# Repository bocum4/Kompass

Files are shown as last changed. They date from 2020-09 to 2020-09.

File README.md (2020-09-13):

  ____   ____   _____ _    _ __  __          
 |  _ \ / __ \ / ____| |  | |  \/  |   /\    
 | |_) | |  | | |    | |  | | \  / |  /  \   
 |  _ <| |  | | |    | |  | | |\/| | / /\ \  
 | |_) | |__| | |____| |__| | |  | |/ ____ \ 
 |____/ \____/ \_____|\____/|_|  |_/_/    \_\

KOMPASS DIGITAL MINI SYTNH.

Related Project Files. 

Este proyecto está basado en el Nebulophone de Dr. Bleep (Nos quitamos el sombrero ante su ingenio). 

https://bleeplabs.com/product/nebulophone/

Se modificó el ruteo de los pines del ATMega para permitir la adición de un sensor capacitivo MPR121
como motor principal del teclado háptico y re-diseñamos la interfaz según nuestros intereses. Todos 
los archivos de programación y manufactura se hacen disponibles aquí bajo la misma licencia 
del proyecto original. 

Creative Commons Attribution-ShareAlike 3.0 Unported License 

Para mas info: contacto@bocuma.mx 

#somosbocuma

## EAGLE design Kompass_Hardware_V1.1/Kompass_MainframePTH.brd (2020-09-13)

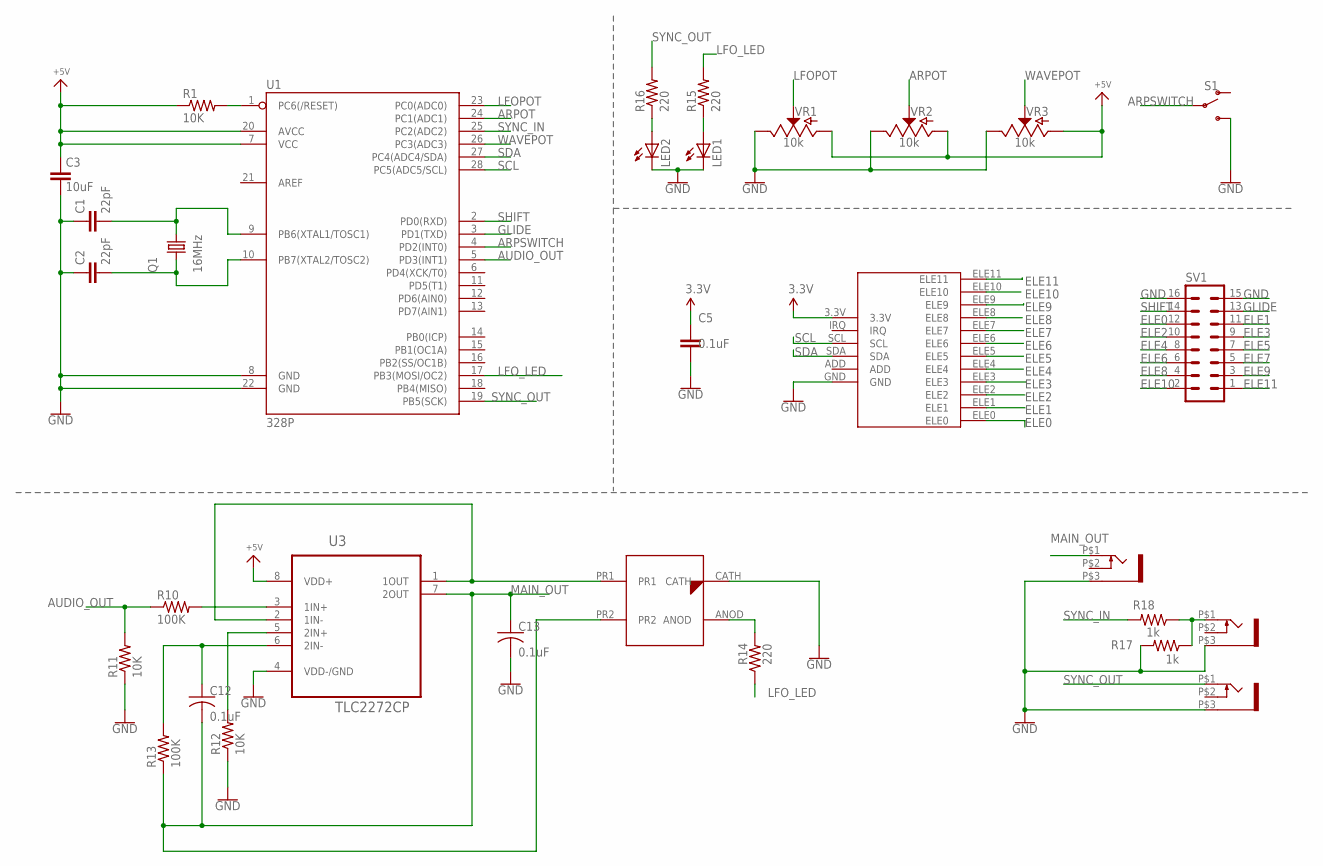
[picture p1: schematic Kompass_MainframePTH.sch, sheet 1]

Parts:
C1, C2: 22pF; C2.5-3
C3: 10uF; C025-025X050
C5: 0.1uF; C2.5-3
C12, C13: 0.1uF; C025-024X044
LED1, LED2: LED3MM
Q1: 16MHz; HC49/S
R1, R11, R12: 10K; 0204/5
R10, R13: 100K; 0204/5
R14, R15, R16: 220; 0204/5
R17, R18: 1k; 0204/5
S1: SWITCH-SPDT-PTH-11.6X4.0MM; SWITCH_SPDT_PTH_11.6X4.0MM
SV1: MA08-2
U1: 328P; DIP28
U3: TLC2272CP; DIP254P762X508-8
U$1: BOCUMA_VACTROLBMA_VACTROL_PTH; BOCUMA_VACTROL
U$2, U$3, U$4: WQP-PJ301M-12_JACK
U$6: MPR121_BREAKOUT
VR1, VR2, VR3: 10k; POT-PTH-ALPS

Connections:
3.3V: C5.1, U$6.3.3V; also elsewhere on the board
ARPOT: U1.24 (PC1(ADC1)), VR2.P$2 (S)
ARPSWITCH: S1.2, U1.4 (PD2(INT0))
AUDIO_OUT: R10.1, R11.2, U1.5 (PD3(INT1))
ELE0: SV1.12, U$6.ELE0
ELE1: SV1.11, U$6.ELE1
ELE2: SV1.10, U$6.ELE2
ELE3: SV1.9, U$6.ELE3
ELE4: SV1.8, U$6.ELE4
ELE5: SV1.7, U$6.ELE5
ELE6: SV1.6, U$6.ELE6
ELE7: SV1.5, U$6.ELE7
ELE8: SV1.4, U$6.ELE8
ELE9: SV1.3, U$6.ELE9
ELE10: SV1.2, U$6.ELE10
ELE11: SV1.1, U$6.ELE11
GLIDE: SV1.13, U1.3 (PD1(TXD))
GND: C1.1, C2.1, C3.2, C5.2, C13.2, LED1.K (C), LED2.K (C), R11.1, R12.1, R17.2, S1.3 (S), SV1.15, SV1.16, U1.8 (GND), U1.22 (GND), U3.4 (VDD-/GND), U$1.CATH, U$2.P$3 (1), U$3.P$3 (1), U$4.P$3 (1), U$6.GND, VR1.P$1 (E), VR2.P$1 (E), VR3.P$1 (E); also elsewhere on the board
LFOPOT: U1.23 (PC0(ADC0)), VR1.P$2 (S)
LFO_LED: R14.1, R15.2, U1.17 (PB3(MOSI/OC2))
MAIN_OUT: C12.2, C13.1, R13.1, U3.7 (2OUT), U$1.PR2, U$4.P$1 (2)
unnamed: C1.2, Q1.2, U1.9 (PB6(XTAL1/TOSC1))
unnamed: C2.2, Q1.1, U1.10 (PB7(XTAL2/TOSC2))
unnamed: R1.2, U1.1 (PC6(/RESET))
unnamed: C12.1, R13.2, U3.6 (2IN-)
unnamed: R12.2, U3.5 (2IN+)
unnamed: U3.1 (1OUT), U3.2 (1IN-), U$1.PR1
unnamed: R10.2, U3.3 (1IN+)
unnamed: R14.2, U$1.ANOD
unnamed: LED1.A, R15.1
unnamed: LED2.A, R16.1
unnamed: R17.1, R18.1, U$2.P$1 (2)
SCL: U1.28 (PC5(ADC5/SCL)), U$6.SCL
SDA: U1.27 (PC4(ADC4/SDA)), U$6.SDA
SHIFT: SV1.14, U1.2 (PD0(RXD))
SYNC_IN: R18.2, U1.25 (PC2(ADC2))
SYNC_OUT: R16.2, U1.19 (PB5(SCK)), U$3.P$1 (2)
VCC: C3.1, R1.1, U1.7 (VCC), U1.20 (AVCC), U3.8 (VDD+), VR1.P$3 (A), VR2.P$3 (A), VR3.P$3 (A); also elsewhere on the board
WAVEPOT: U1.26 (PC3(ADC3)), VR3.P$2 (S)

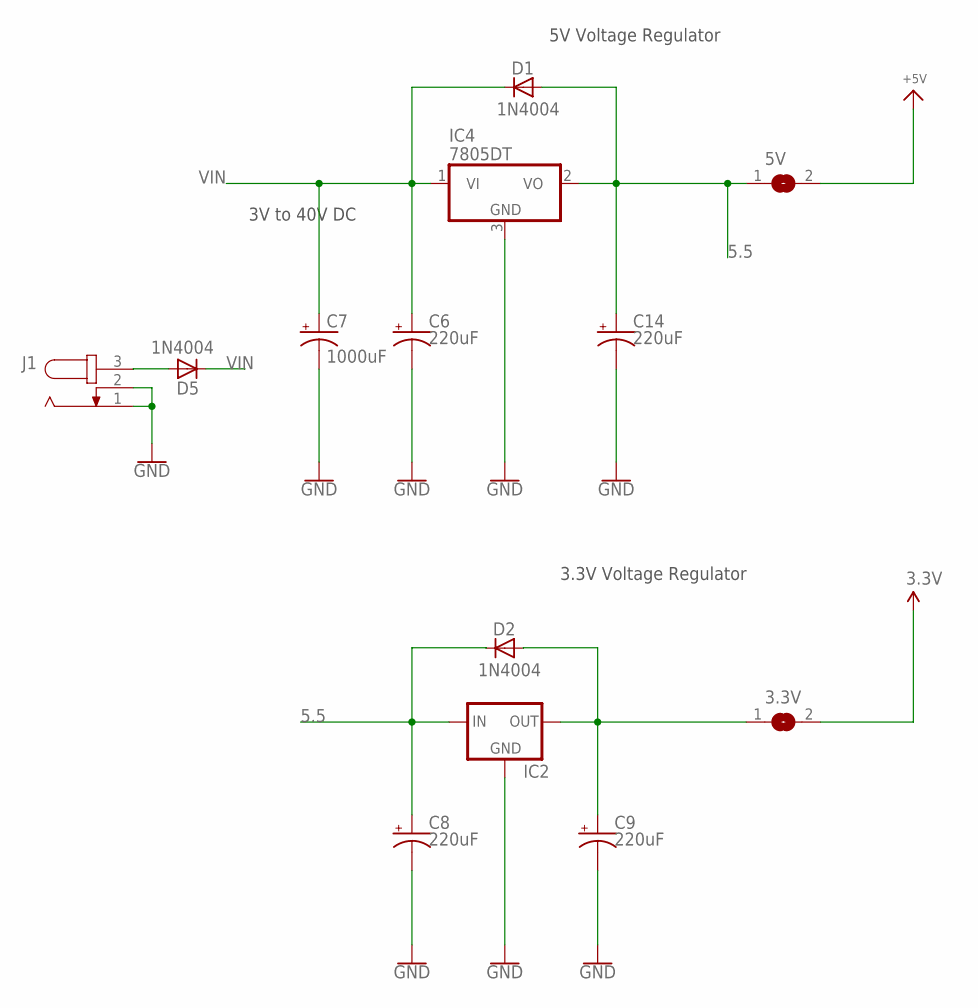
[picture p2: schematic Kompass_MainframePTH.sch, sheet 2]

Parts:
3.3V, 5V: SJW
C6, C8, C9, C14: 220uF; E2,5-6E
C7: 1000uF; E3,5-8
D1, D2, D5: 1N4004; DO41-10
IC2: 78LXX
IC4: 7805DT; TO252
J1: JACK-PLUG0; SPC4077

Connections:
3.3V: 3.3V.2; also elsewhere on the board
5.5: 5V.1, C8.+, C14.+, D1.A, D2.C, IC2.IN, IC4.2 (VO)
GND: C6.-, C7.-, C8.-, C9.-, C14.-, IC2.GND, IC4.3 (GND), J1.1, J1.2; also elsewhere on the board
unnamed: D5.A, J1.3
unnamed: 3.3V.1, C9.+, D2.A, IC2.OUT
VCC: 5V.2; also elsewhere on the board
VIN: C6.+, C7.+, D1.C, D5.C, IC4.1 (VI)

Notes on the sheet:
5V Voltage Regulator
3V to 40V DC
3.3V Voltage Regulator

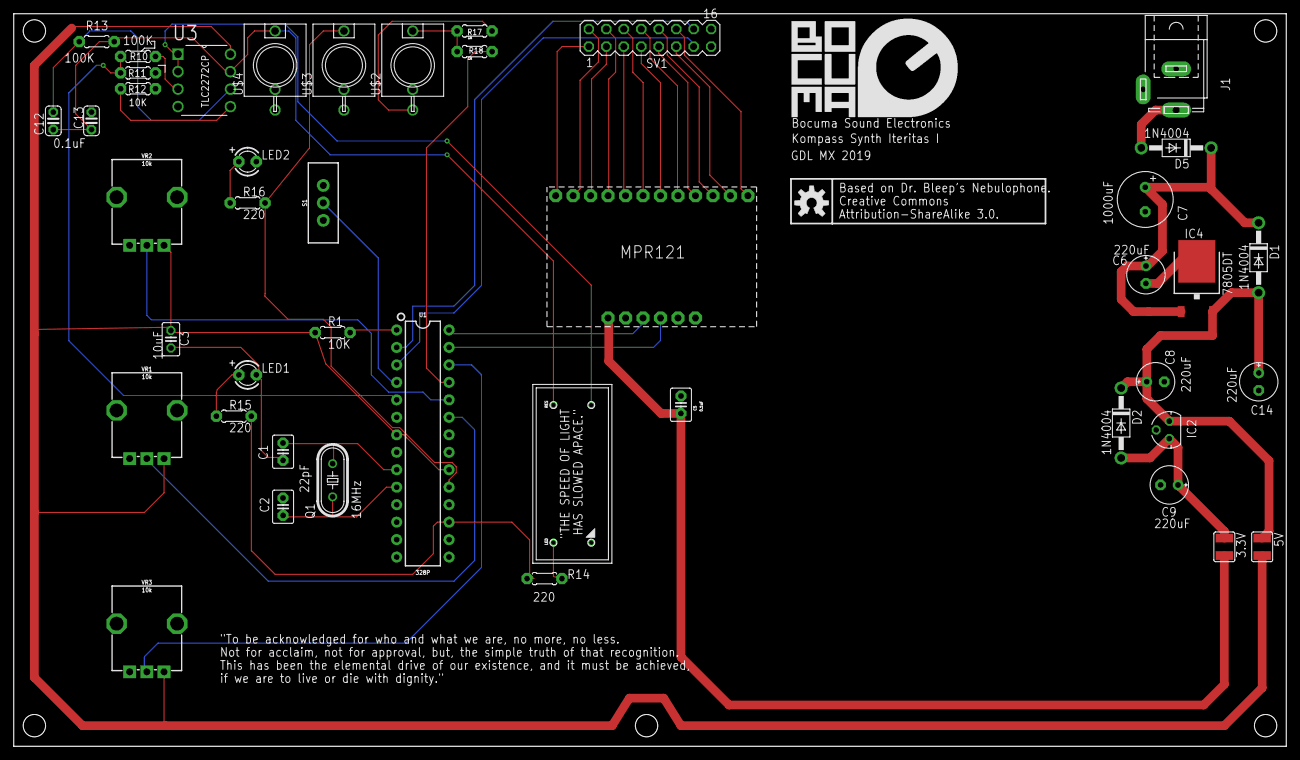
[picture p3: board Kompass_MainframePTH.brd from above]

Board: 2 copper layers, 185.0 x 106.5 mm, 45 parts (0 on the bottom side), 43 nets.

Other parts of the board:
U$5: OSHW-LOGO-M

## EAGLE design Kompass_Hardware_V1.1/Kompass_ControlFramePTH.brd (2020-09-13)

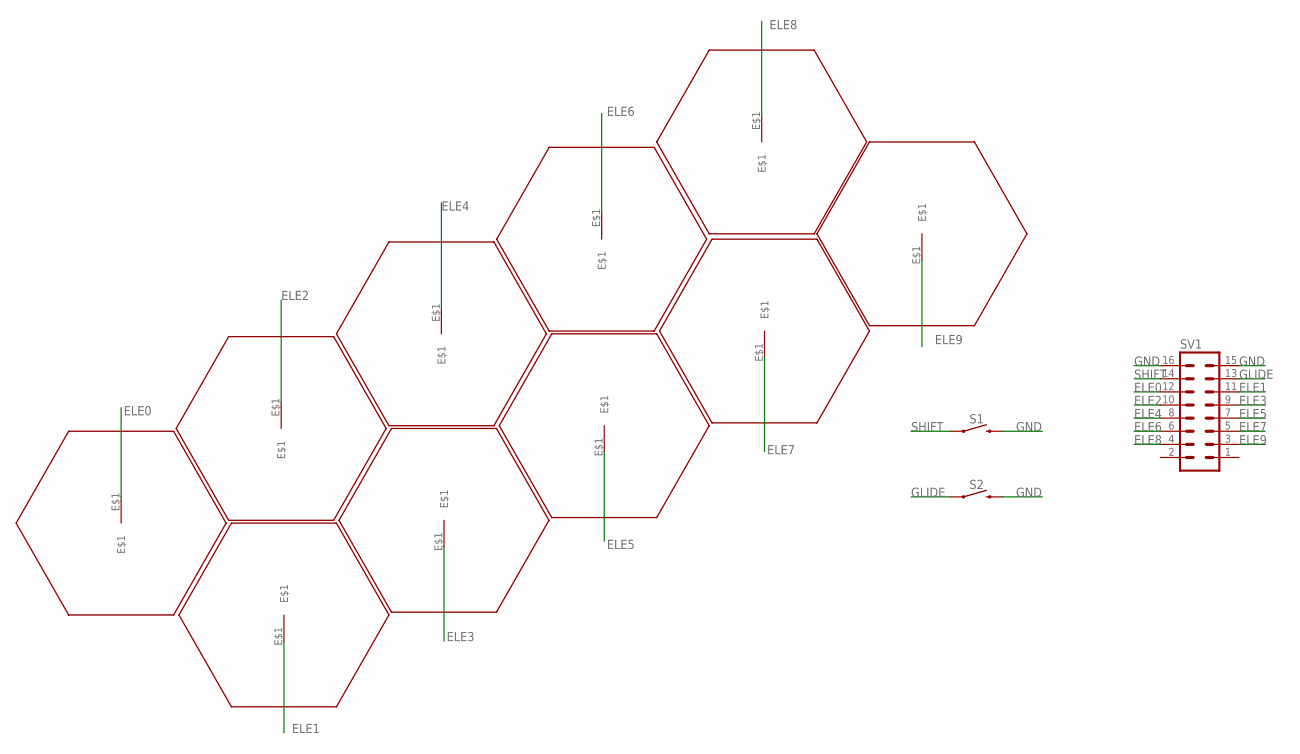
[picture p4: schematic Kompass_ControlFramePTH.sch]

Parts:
ELE0, ELE1, ELE2, ELE3, ELE4, ELE5, ELE6, ELE7, ELE8, ELE9: HEX_ELECTRODEHEX_ELECTRODEPAD; HEX_ELECTRODE
S1, S2: MOMENTARY-SWITCH-SPST-PTH-6.0MM-KIT; TACTILE_SWITCH_PTH_6.0MM_KIT
SV1: MA08-2

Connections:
ELE0: ELE0.E$1, SV1.12
ELE1: ELE1.E$1, SV1.11
ELE2: ELE2.E$1, SV1.10
ELE3: ELE3.E$1, SV1.9
ELE4: ELE4.E$1, SV1.8
ELE5: ELE5.E$1, SV1.7
ELE6: ELE6.E$1, SV1.6
ELE7: ELE7.E$1, SV1.5
ELE8: ELE8.E$1, SV1.4
ELE9: ELE9.E$1, SV1.3
GLIDE: S2.1, SV1.13
GND: S1.3 (2), S2.3 (2), SV1.15, SV1.16
SHIFT: S1.1, SV1.14

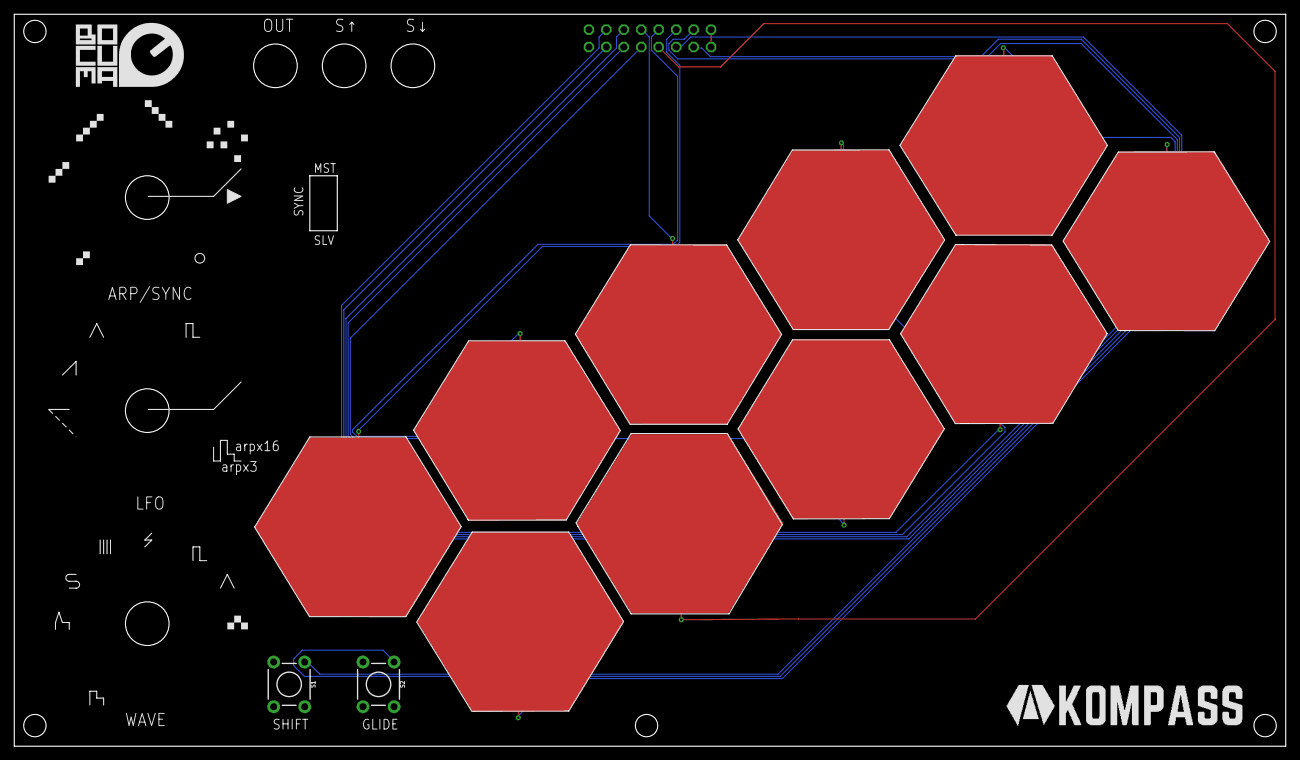
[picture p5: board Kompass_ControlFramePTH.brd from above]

Board: 2 copper layers, 185.0 x 106.5 mm, 13 parts (0 on the bottom side), 13 nets.

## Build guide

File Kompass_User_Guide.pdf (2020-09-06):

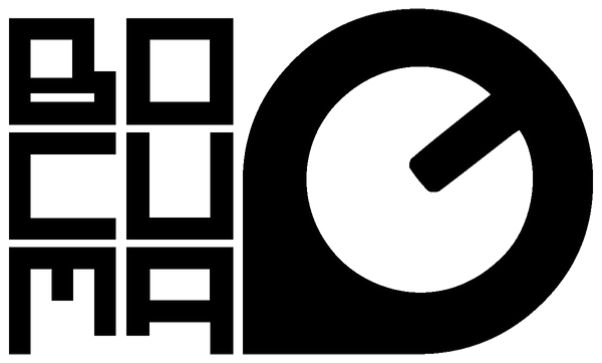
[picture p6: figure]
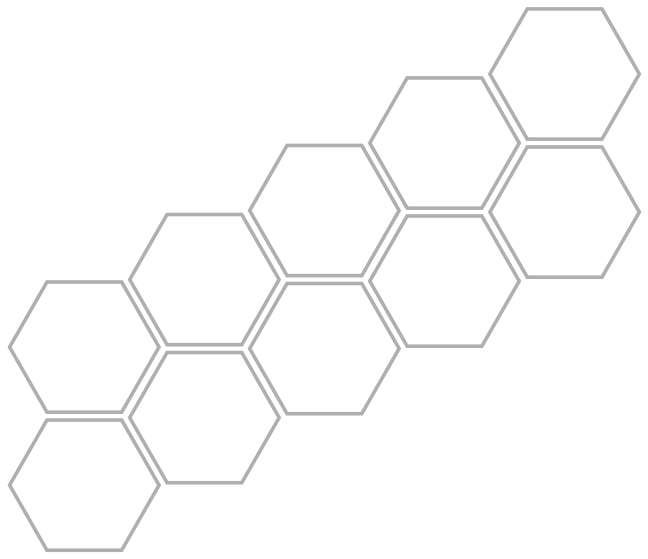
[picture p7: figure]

GUIA DE USUARIO.

> BOCUMA SOUND ELECTRONICS.
> Bash console: system status ok.
> OS: Bocuma OS V1.0, generic Kernel. > Connection established.

> sudo get Kompass_User_Guide

> Downloading Kompass_User_Guide...

> Progress: ||||||||||||||||||||| 100%

## < BOCUMA SOUND ELECTRONICS >

## <INTRO>

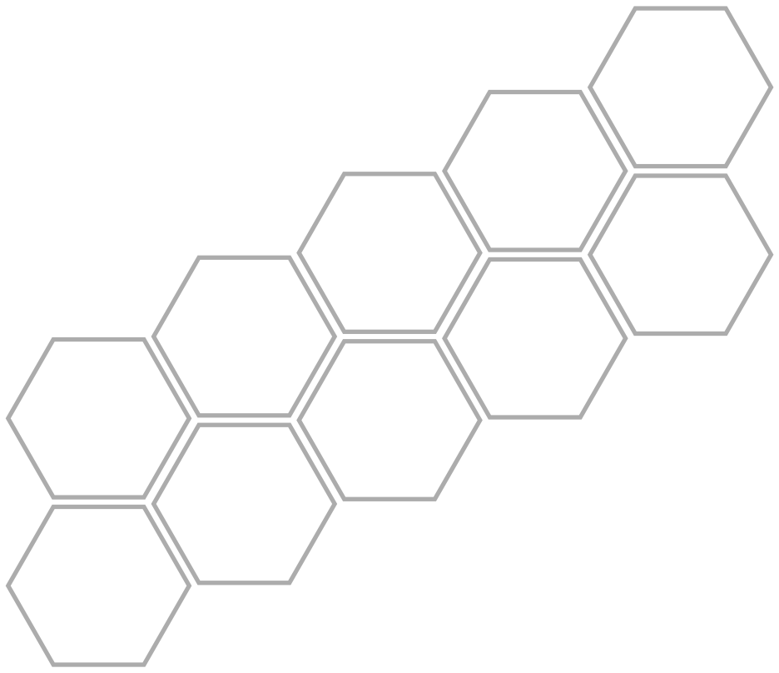
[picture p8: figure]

Felicidades por tu adquisición de un KOMPASS DIGITAL MINI SYNTH.

Esta | guía | de | usuario | está | pensada | para
visualizarse en un dispositivo móvil, de tal manera que puedas seguirla con facilidad mientras experimentas con tu setup.

Hemos diseñado a KOMPASS con el performance y la tactilidad en mente, dotándolo de un teclado capacitivo de 10 notas, multiples formas de onda, un LFO y un Arpeggiador.

El rápido proceso creativo fue posible gracias al increíble trabajo de John-Mike Reed de Bleep Labs, cuyo trabajo publicado en creative commons nos abrió las puertas a un nuevo mundo de exploración tecnológica orientada al sonido. Estas indagaciones nos apasionan y es por ello que nos emociona mucho ponerlas a tu alcance. (https://bleeplabs.com/)

## <SPECS>

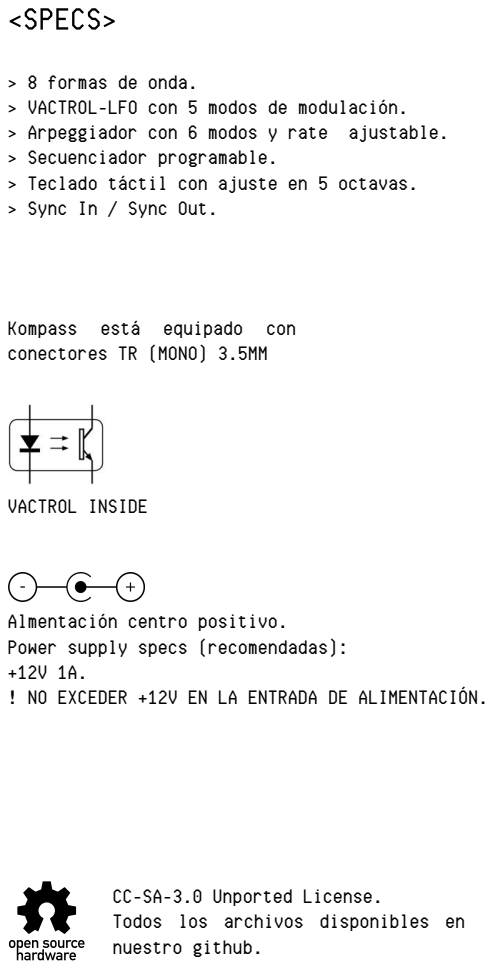
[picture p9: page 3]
VACTROL INSIDE

> 8 formas de onda.
> VACTROL-LFO con 5 modos de modulación.
> Arpeggiador con 6 modos y rate ajustable.
> Secuenciador programable.
> Teclado táctil con ajuste en 5 octavas.
> Sync In / Sync Out. (https://bleeplabs.com/)

Kompass está equipado con
conectores TR (MONO) 3.5MM

Almentación centro positivo.
Power supply specs (recomendadas):
! NO EXCEDER +12V EN LA ENTRADA DE ALIMENTACIÓN. (https://bleeplabs.com/)

CC-SA-3.0 Unported License.
Todos los archivos disponibles en
nuestro github. (https://github.com/TBocuma)

## <AFINACIÓN>

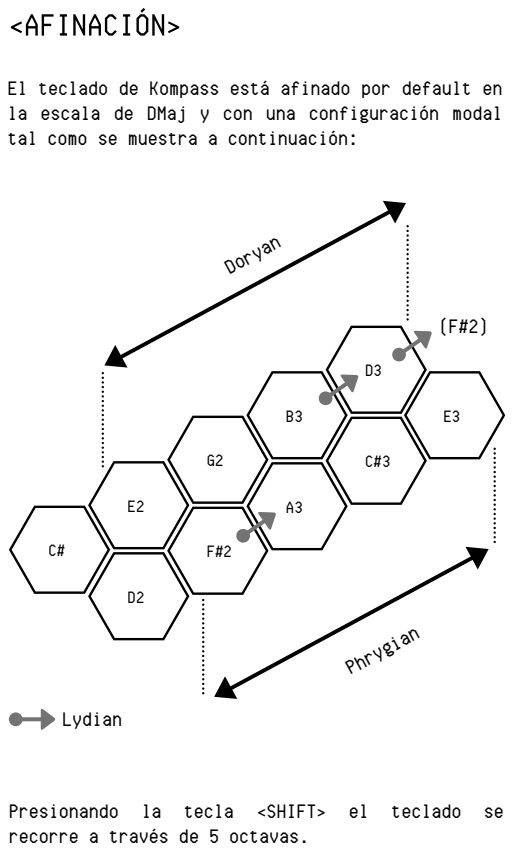
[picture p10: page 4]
Doryan; Phrygian; Lydian

El teclado de Kompass está afinado por default en
la escala de DMaj y con una configuración modal
tal como se muestra a continuación:

Presionando la tecla <SHIFT> el teclado se
recorre a través de 5 octavas. (https://bleeplabs.com/)

## <WAVE KNOB>

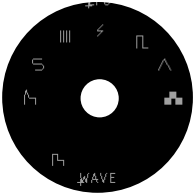
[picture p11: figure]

Pueden | seleccionarse | 8
formas de onda o señales de origen diferentes.

El release cambia de "corto" a "largo" según se vaya
recorriendo el knob dentro de la selección. (https://bleeplabs.com/)

## <LFO KNOB>

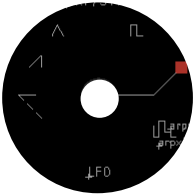
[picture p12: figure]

Pueden | seleccionarse | 4
modulaciones para el LFO y adicionalmente, 2 divisiones
según | el | tempo | del
Arpeggiador.

La velocidad de modulación cambia de "lento" a "rápido"
según | se vaya recorriendo
el | knob | dentro | de | la
selección. (https://bleeplabs.com/)

## <ARP KNOB>

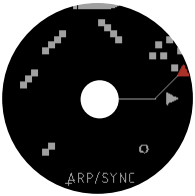
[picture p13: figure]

Pueden | seleccionarse | 5
arpeggios distintos y de
igual manera, aumentar la
velocidad según se recorra el knob. (https://bleeplabs.com/)

## <ARP Y SYNC>

El control switch <SYNC> permite alternar el clock de KOMPASS entre el modo "MST" (maestro) y "SLV" (esclavo).

> Modo maestro: en este modo KOMPASS se rige mediante su CLK interno, cuyo rate se controla por el knob <ARP/SYNC>. La señal de CLK interno se envía también hacía el conector SYNC OUT.

> Modo esclavo: en este modo KOMPASS se rige mediante la señal de CLK proveniente del conector SYNC IN.

AUDIO OUT / SYNC OUT / SYNC IN (https://bleeplabs.com/)

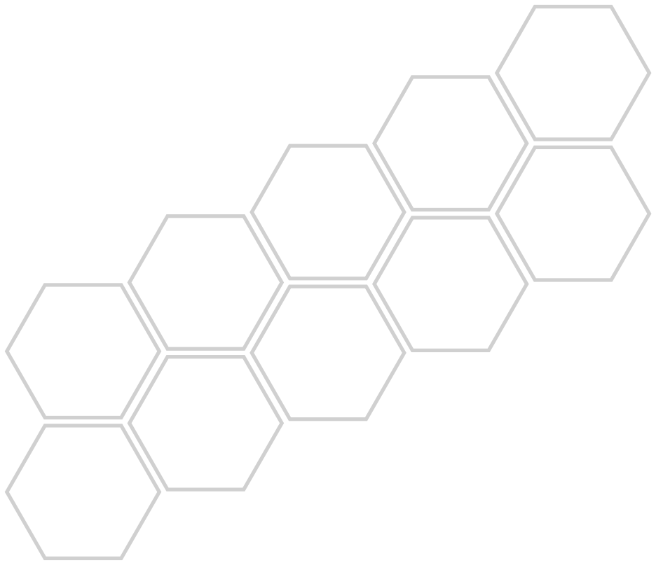
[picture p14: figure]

## <ARP REC>

Kompass es capaz de grabar secuencias dentro de la memoria de su arpeggiador.

Para programar una secuencia:

> Con el selector <SYNC> en modo SLV (esclavo) gira el knob <ARP/SYNC> completamente hacia la derecha (simbolo "º"), la luz led correspondiente cambiará ligeramente su intensidad.

> | Presiona | el | botón | <SHIFT>, | la | luz | led
correspondiente recobrará su brillo original para indicar el inicio del modo de grabación.

> Toca el teclado hexagonal para grabar la secuencia. Puedes insertar una pausa con el botón <GLIDE>. Se pueden secuenciar hasta 32 beats en total.

> Para reproducir la secuencia, coloca la perilla <ARP/SYNC> en el simbolo de "play" (►) y

presiona cualquier hexágono. La secuencia se reproducirá a partir del hexágono presionado.

> La secuencia permanecerá en la memoria hasta que realices una nueva grabación o apagues la unidad.

> La secuencia puede sincronizarse utilizando el CLK interno de KOMPASS (modo MST del selector <SYNC>) o con una señal externa proveniente del conector SYNC IN (modo SLV del selector <SYNC>). (https://bleeplabs.com/)

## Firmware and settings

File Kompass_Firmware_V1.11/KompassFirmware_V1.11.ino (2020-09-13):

/*
 
  _ )    _ \     __|   |  |    \  |     \   
  _ \   (   |   (      |  |   |\/ |    _ \  
 ___/  \___/   \___|  \__/   _|  _|  _/  _\ 
 Sound Electronics | bocuma.mx

KOMPASS FIRMWARE CODE V0.2
BASED ON: NEBULOPHONE code v11 by Dr. Bleep
bleeplabs.com

DDS:
 http://mouro.info/signal-generator-using-arduino-and-dds/
 http://interface.khm.de/index.php/lab/experiments/arduino-dds-sinewave-generator/
 http://www.analog.com/library/analogdialogue/archives/38-08/dds.html

Setting up timers.
 http://www.cs.mun.ca/~rod/Winter2007/4723/notes/timer0/timer0.html
 http://arcfn.com/2009/07/secrets-of-arduino-pwm.html
 http://blog.wingedvictorydesign.com/2009/05/29/generate-real-time-audio-on-the-arduino-using-pulse-code-modulation/2/

Also good to know:
 http://billgrundmann.wordpress.com/2009/03/03/to-use-or-not-use-writedigital/


 */
#include <avr/pgmspace.h>
//#include <MemoryFree.h>

/////////////////////////////////
//Capacitive keyboard additions:
#include <Wire.h>
#include "Adafruit_MPR121.h"
#ifndef _BV
#define _BV(bit) (1 << (bit)) 
#endif
Adafruit_MPR121 cap = Adafruit_MPR121();
/////////////////////////////////

unsigned long chromatic[] = {

  2750, 2914, 3087, 3270, 3465, 3671, 3889, 4120, 4365, 4625, 4900, 5191, 5500, 5827, 6174, 6541, 6930, 7342, 7778,
  8241, 8731, 9250, 9800, 10383, 11000, 11654, 12347, 13081, 13859, 14683, 15556, 16481, 17461, 18500, 19600,
  20765, 22000, 23308, 24694, 26163, 27718, 29367, 31113, 32963, 34923, 36999, 39200, 41531, 44000, 46616, 49388,
  52325, 55437, 58733, 62225, 65926, 69846, 73999, 78399, 83061, 88000, 93233, 98777, 104650, 110873, 117466,
  124451, 131851, 139691, 147998, 156798, 166122, 176000, 186466, 197553, 209300, 221746, 234932, 248902, 263702,
  279383, 295996, 313596, 332244, 352000, 372931, 395107, 418601

};
int scale[] = {
  0, 2, 4, 5, 7, 9, 11, 12, 14, 16, 17, 19, 21, 23, 24, 26, 28, 29, 31, 33, 35, 36, 38, 40, 41, 43, 45, 47, 48, 50, 52, 53, 55, 57, 59, 60, 62, 64
};


unsigned long counter, cprev1, cprev2;
unsigned long freq, freq2, keyfreq;

byte n = 1;
int keypress, kh, prevkh2, prevkeypress2;
int prevn;
int prevkeypress, prevattackmode;
int keyr1, keyr0, keyra, keyrw, keyrw2;
int waveselect, subwaveselect, prevwavepot;
int r, r2;
int i = 1;
long prev;
long prev4;

int irin;
int irout;
long irtempo;
int ir = 0;
long previrtempo = 1;
long previr = 0;
int arpselect;
byte count = 0;
int a = 0;
int key = 1;
int d;
int s;
int lforate;
int lforateC;
int lfo = 0;
int l = 0;
int j = 10;
int r3;
byte dronemode = 3;
byte dronemodebutton, prevdronemodebutton;
int irtempomod;
int irswitch;
int arprate = 10;
int arprateF;
int arprateL;
int keyoffset = 0;

byte scan = 1;
byte shiftbutton;
byte prevshiftbutton;
int shift = 0;
int maxrelease = 250;
int maxbrightness = 84;
int keym;
int prevarprateF;
int glide = 3;
byte keyp;
byte keyc;
int remember[2];
int h = 0;
long frequencyout;
long frequencyp;
long g;
long  f;
int gliderate;
long prev9;
int k;
int glidebutton;
int prevglidebutton;
int c = 1;
int b;
int maxwaveindex = 15;
int temp;
int release, releasem, releaseb;
int releaselength;
int ampholder = 1;
int previrin;
static int oscc, oscx, oscy, oscz, oscb, oscxb;
float amp = 1;
int wavepot, arppot, lfopot;
int himap, lowmap, lowf, hif, himap2, lowmap2;
int pwmPin = 3;
int ampm, ampb, read0, read1;
int arpcount, arp;
volatile unsigned long accumulator = 0;
volatile unsigned long accumulator2 = 0;
volatile unsigned long accumulator3 = 0;
volatile unsigned long accumulator4 = 0;
volatile unsigned long accumulator5 = 0;
volatile unsigned long increment = 0;
volatile unsigned long increment2 = 0;
volatile unsigned long increment3 = 0;
volatile unsigned long increment4 = 0;
volatile unsigned long increment5 = 0;
volatile unsigned long increment6 = 0;
volatile unsigned long increment7 = 0;


long prev8;
int incrementb = 0;
unsigned long holder4;
unsigned long holder3;
unsigned long holder2;
unsigned long holder;
int offx;
byte index = 0;
byte index2 = 0;
byte index3 = 0;
byte index4 = 0;
byte indexb = 0;
byte index5 = 0;
long frequency, frequencyc, frequency2, frequency2c, frequencyouta, frequencycs, frequencyps, temppot;
int rint, indexi;
int noise = 0;
int wrc, cnw, apot, waveB, waveoff;
float bpotf;
int drone;
int acc = 8;
int oscmode = 1;
int ircount;
//long tempobank[4];
int aread, oscsel;
int oscswitch = 1;
uint16_t osc, oscj, uosc, wr, wr2, rosc, bswitch;
int xpot;
int up = 1;
int tempermentbutton, shiftcount;
int temperment = 1;
int offsetpot = 5;
int keypot = 0;
int keypotm = 0;
int tunemode = 0;
int attackmode;
int attacklength;
int upa = 1, upb = 1, upc = 1;
int toplatcha = 0;
int attackon = 0;
unsigned long prev2, prev3;
int keydown, counta, prevkeydown;
//long tune;
int maxarp = 306;
unsigned long frequencya, frequencyw, frequencyw2;
int attackp;
long attacka, attackw, wavemod;
long gstep;
unsigned int lfsr = 1;
unsigned int lfsr2 = 1;
unsigned bitholder, bitholder2;
volatile byte icnt1, icnt2, ms, noisecount;
int keysb, keysd, keypressb, keypressd, prevkeypressb, prevkeypressd, prevkh;
int scount;
int gauge, spd;
long sprev;
int restbutton = 1,      recordbutton = 1, prevrestbutton,      prevrecordbutton ;
int record, rcount = 1, recordlatch, prevrcount, resta = 0;
int recordbank[32] = {2, 63, 5, 63, 10, 63, 5, 63, 1, 63, 63, 63, 10, 63, 63, 63};
int rplace, rest = 0, rstop = 8, prevrecord;
byte bhold;
volatile long whatok, whatno;
int i1, i2, i3, i4, tria;
byte b1, b2, b3, b4;
int epot, dswitch, noisekey, rarp;
long fpot, bpot, gpot, recordinput;
long thecount;
const  char  waveTable[] PROGMEM =


{
  0, 0, 0, 0, 0, 0, 0, 0, 0, 0, 0, 0, 0, 0, 0, 0, 0, 0, 0, 0, 0, 0, 0, 0, 0, 0, 0, 0, 0, 0, 0, 0, 0, 0, 0, 0, 0, 0, 0, 0, 0, 0, 0, 0, 0, 0, 0, 0, 0, 0, 0, 0, 0, 0, 0, 0, 0, 0, 0, 0, 0, 0, 0, 0,
  0, 0, 0, 0, 0, 0, 0, 0, 0, 0, 0, 0, 0, 0, 0, 0, 0, 0, 0, 0, 0, 0, 0, 0, 0, 0, 0, 0, 0, 0, 0, 0, 0, 0, 0, 0, 0, 0, 0, 0, 0, 0, 0, 0, 0, 0, 0, 0, 0, 0, 0, 0, 0, 0, 0, 0, 0, 0, 0, 0, 0,
  0, 0, 0, 0, 0, 0, 0, 0, 0, 0, 0, 0, 0, 0, 0, 0, 0, 0, 0, 0, 0, 0, 0, 0, 0, 0, 0, 0, 0, 0, 0, 0, 0, 0, 0, 0, 0, 0, 0, 0, 0, 0, 0, 0, 0, 0, 0, 0, 0, 0, 0, 0, 0, 0, 0, 0, 0, 0, 0, 0, 0,
  0, 0, 0, 0, 0, 0, 255, 255, 255, 255, 255, 255, 255, 255, 255, 255, 255, 255, 255, 255, 255, 255, 255, 255, 255, 255, 255, 255, 255, 255, 255, 255, 255, 255,
  255, 255, 255, 255, 255, 255, 255, 255, 255, 255, 255, 255, 255, 255, 255, 255, 255, 255, 255, 255, 255, 255, 255, 255, 255, 255, 255, 255, 255, 255, 255,
  255, 255, 255, 255, 255, 255, 255, 255, 255, 255, 255, 255, 255, 255, 255, 255, 255, 255, 255, 255, 255, 255, 255, 255, 255, 255, 255, 255, 255, 255, 255,
  255, 255, 255, 255, 255, 255, 255, 255, 255, 255, 255, 255, 255, 255, 255, 255, 255, 255, 255, 255, 255, 255, 255, 255, 255, 255, 255, 255, 255, 255, 255,
  255, 255, 255, 255, 255, 255,

  1, 1, 2, 3, 4, 5, 6, 7, 8, 9, 10, 11, 12, 13, 14, 15, 16, 17, 18, 19, 20, 21, 22, 23, 24, 25, 26, 27, 28, 29, 30, 31, 32, 33, 34, 35, 36, 37, 38, 39, 40, 41, 42, 43, 44, 45, 46, 47, 48, 49, 50, 51, 52, 53, 54, 55, 56, 57, 58, 59, 60,
  61, 62, 63, 64, 65, 66, 67, 68, 69, 70, 71, 72, 73, 74, 75, 76, 77, 78, 79, 80, 81, 82, 83, 84, 85, 86, 87, 88, 89, 90, 91, 92, 93, 94, 95, 96, 97, 98, 99, 100, 101, 102, 103, 104, 105, 106, 107, 108, 109, 110, 111, 112, 113,
  114, 115, 116, 117, 118, 119, 120, 121, 122, 123, 124, 125, 126, 127, 128, 129, 130, 131, 132, 133, 134, 135, 136, 137, 138, 139, 140, 141, 142, 143, 144, 145, 146, 147, 148, 149, 150, 151, 152, 153, 154, 155, 156,
  157, 158, 159, 160, 161, 162, 163, 164, 165, 166, 167, 168, 169, 170, 171, 172, 173, 174, 175, 176, 177, 178, 179, 180, 181, 182, 183, 184, 185, 186, 187, 188, 189, 190, 191, 192, 193, 194, 195, 196, 197, 198, 199,
  200, 201, 202, 203, 204, 205, 206, 207, 208, 209, 210, 211, 212, 213, 214, 215, 216, 217, 218, 219, 220, 221, 222, 223, 224, 225, 226, 227, 228, 229, 230, 231, 232, 233, 234, 235, 236, 237, 238, 239, 240, 241, 242,
  243, 244, 245, 246, 247, 248, 249, 250, 251, 252, 253, 254,

  1, 3, 5, 7, 9, 11, 13, 15, 17, 19, 21, 23, 25, 27, 29, 31,
  33, 35, 37, 39, 41, 43, 45, 47, 49, 51, 53, 55, 57, 59, 61, 63, 65,
  67, 69, 71, 73, 75, 77, 79, 81, 83, 85, 87, 89, 91, 93, 95, 97, 99,
  101, 103, 105, 107, 109, 111, 113, 115, 117, 119, 121, 123, 125, 127, 129, 131, 133,
  135, 137, 139, 141, 143, 145, 147, 149, 151, 153, 155, 157, 159, 161, 163, 165, 167,
  169, 171, 173, 175, 177, 179, 181, 183, 185, 187, 189, 191, 193, 195, 197, 199, 201,
  203, 205, 207, 209, 211, 213, 215, 217, 219, 221, 223, 225, 227, 229, 231, 233, 235,
  237, 239, 241, 243, 245, 247, 249, 251, 253, 255, 254, 252, 250, 248, 246, 244, 242,
  240, 238, 236, 234, 232, 230, 228, 226, 224, 222, 220, 218, 216, 214, 212, 210, 208,
  206, 204, 202, 200, 198, 196, 194, 192, 190, 188, 186, 184, 182, 180, 178, 176, 174,
  172, 170, 168, 166, 164, 162, 160, 158, 156, 154, 152, 150, 148, 146, 144, 142,
  140, 138, 136, 134, 132, 130, 128, 126, 124, 122, 120, 118, 116, 114, 112, 110, 108,
  106, 104, 102, 100, 98, 96, 94, 92, 90, 88, 86, 84, 82, 80, 78, 76, 74, 72, 70, 68, 66,
  64, 62, 60, 58, 56, 54, 52, 50, 48, 46, 44, 42, 40, 38, 36, 34, 32, 30, 28, 26, 24, 22,
  20, 18, 16, 14, 12, 10, 8, 6, 4, 2, 0,
};

void setup(void)

{
  //CapSensor Begin:
  cap.begin();
  //Serial.begin(9600);
  pinMode(1, INPUT);
  pinMode(0, INPUT);

  pinMode(2, INPUT);
  pinMode(4, INPUT);
  pinMode(5, INPUT);
  pinMode(6, INPUT);
  pinMode(7, INPUT);
  pinMode(8, INPUT);
  pinMode(9, INPUT);
  pinMode(10, INPUT);
  pinMode(12, INPUT);
  pinMode(14, INPUT);
  pinMode(15, INPUT);
  pinMode(3, OUTPUT);
  pinMode(13, OUTPUT); // IR out
  pinMode(11, OUTPUT); // LFO LED out

  digitalWrite(1, HIGH);
  digitalWrite(0, HIGH);

  digitalWrite(2, HIGH);
  digitalWrite(4, HIGH);
  digitalWrite(5, HIGH);
  digitalWrite(6, HIGH);
  digitalWrite(7, HIGH);
  digitalWrite(8, HIGH);
  digitalWrite(9, HIGH);
  digitalWrite(10, HIGH);
  digitalWrite(12, HIGH);
  digitalWrite(14, HIGH);
  digitalWrite(15, HIGH);

  randomSeed(analogRead(1));


  if (digitalRead(0) == LOW) {
    oscswitch = 2;
  }
  else oscswitch = 1;

#define cbi(sfr, bit) (_SFR_BYTE(sfr) &= ~_BV(bit))
#define sbi(sfr, bit) (_SFR_BYTE(sfr) |= _BV(bit))


  sbi (TIMSK2, TOIE2);

  sbi (TCCR2B, CS20);
  cbi (TCCR2B, CS21);
  cbi (TCCR2B, CS22);

  cbi (TCCR2A, COM2A0);  // clear Compare Match
  sbi (TCCR2A, COM2A1);
  sbi (TCCR2A, COM2B1);

  sbi (TCCR2A, WGM20);  // Mode 1  / Phase Correct PWM
  cbi (TCCR2A, WGM21);
  cbi (TCCR2B, WGM22);

}


////////////////////////////////////////////////////////////////////////////////////////////////////////////////////

ISR(TIMER2_OVF_vect)
{ 



  if (oscswitch ==1){   //STANDARD MODE



    if (oscsel==1){  //single wave
     OCR2B =((osc)*release)>>8;
      accumulator += increment; 
      index=(accumulator >> 24);  
releaseb=0;
      accumulator2 += increment2; 
      index2 =(accumulator2 >> 24);  



      osc = pgm_read_byte(&waveTable[index+waveselect]);
      //osc = (((pgm_read_byte(&waveTable[(index2)+64])))/2);
    }
    if (oscsel==2){ // double wave selectable
    OCR2B =((osc)*release)>>8;

      accumulator += increment; 
      index=(accumulator >> 24);  

      accumulator2 += increment2; 
      index2 =(accumulator2 >> 24);  


      osc = (((pgm_read_byte(&waveTable[index+waveselect]))/4)+((pgm_read_byte(&waveTable[(index2)+subwaveselect])))/2);
    }

    if (oscsel==4){ // double wave
    OCR2B =((osc)*release)>>8;

      accumulator += increment; 
      index=(accumulator >> 24);  

      accumulator2 += increment2; 
      index2 =(accumulator2 >> 24);  


      osc = (((pgm_read_byte(&waveTable[index+waveselect]))/2)+((pgm_read_byte(&waveTable[(index2)])))/2);
    }
    if (oscsel==6){ // double wave


      OCR2B =(((osc)-releaseb)*release)>>5;
      accumulator += increment; 
      index=(accumulator >> 24);  




      osc = (pgm_read_byte(&waveTable[index+waveselect]))-tria;
    }


       if (oscsel==3){ //|?\/|/|/\/|/\?|?|?|?\/??|??||?\/\/\//\/ white noise
    OCR2B =((osc)*release)>>8;
      osc=lfsr>>8;
      //  nkey=(major[remember[0]+2])+ keyoffset+offsetpot+keypotm;
      if (freq!=0){
        icnt1++;
        if(icnt1==(remember[1]<<2)-3) {
          bitholder  = ((lfsr >> 0) ^ (lfsr >> 2) ^ (lfsr >> 3) ^ (lfsr >> 5) ) & 1;
          lfsr =  (lfsr >> 1) | (bitholder << 15);
          icnt1=0;
        }

        
        }
        if (freq==0){
          osc=0;
      }



    }
  }

  if (oscswitch==2){ //drone death 40XX


    if (dronemode==0){ //METAL MACHINE
      releaselength=40;
      accumulator += increment>>1; 
      index=(accumulator >> 24);  

      accumulator2 += increment2>>2; 
      index2 =(accumulator2 >> 24);  
      accumulator3 += bpot;

      index3 = (accumulator3) >> 8;
      if(dswitch == 1)
      {
        uosc =((pgm_read_byte(&waveTable[index3+waveoff])))-(((pgm_read_byte( &waveTable[index+waveoff]))*release)>>8);
      }
      if(dswitch == 0)
      {
        uosc =((pgm_read_byte(&waveTable[index3+waveoff])))^(((pgm_read_byte( &waveTable[index+waveoff]))*release)>>8);
      }
    }
    if (dronemode==1){ //detunestep


      uosc = (osc*release)>>8; 
      releaselength=40;

      accumulator5 += increment5; 
      index5=(accumulator5 >> 24);  

      accumulator += increment; 
      index =(accumulator >> 24);  

      if(dswitch == 1)
      {
        osc = (((pgm_read_byte(&waveTable[index5+waveselect])))-((pgm_read_byte(&waveTable[(index+waveselect)]))));
      }
      if(dswitch == 0)
      {
        osc = (((pgm_read_byte(&waveTable[index5+waveselect])))*((pgm_read_byte(&waveTable[(index+waveselect)]))))>>8;
      }





    }

    if (dronemode==2){ //ALL GLORY TO THE NEBULO-TOAD
      releaselength=40;
      accumulator += increment>>1; 
      index=(accumulator >> 24);  

      accumulator2 += increment2>>2; 
      index2 =(accumulator2 >> 24);  
      accumulator3 += bpot;

      b1++;
      b2+=2;
      b3+=3;
      b4+=epot;

      osc =(((pgm_read_byte(&waveTable[waveoff+index^b2^b3])))+(pgm_read_byte( &waveTable[waveoff+index2^b1^b4])));
      uosc = (osc*release)>>8; 

    }

    if (dronemode==3){


      // You broke my master system
      accumulator += increment6; 
      index=(accumulator >> 24);  

      accumulator2 += increment7; 
      index2=(accumulator2 >> 24);  

      if(icnt1++ == (bpot)) {
        bitholder  = ((lfsr >> 0) ^ (lfsr >> 2) ^ (lfsr >> 3) ^ (lfsr >> 5) ) & 1;
        lfsr =  (lfsr >> 1) | (bitholder << 15);
        icnt1=0;
      }


      if ((i2+=4)>(lfsr*bitholder)+1){
        i2=0;
      }
      if ((i3+=6)>(lfsr*2+1)){
        i3=0;
      }
      if ((i4+=32)>((lfsr*16)+1)){
        i4=0;
      }


      if(dswitch == 1) 
      {
        if ((i2+=4)>(lfsr*bitholder)+1){
          i2=0;
        }
        if ((i3+=6)>(lfsr*2+1)){
          i3=0;
        }
        if ((i4+=32)>((lfsr*16)+1)){
          i4=0;
        }
        uosc =(((pgm_read_byte(&waveTable[waveoff+index])))-(pgm_read_byte( &waveTable[waveoff+index2])));
      }
      if(dswitch == 0)

      {
        if ((i2+=2)>(lfsr)+1){
          i2=0;
        }
        if ((i3+=2)>(lfsr*2+1)){
          i3=0;
        }
        if ((i4+=16)>((lfsr*2)+1)){
          i4=0;
        }

        uosc =(((pgm_read_byte(&waveTable[waveoff+index])))-(pgm_read_byte( &waveTable[waveoff+index2])));
      }

    }


    if (dronemode>=4){

      dronemode=0;
    }
    OCR2B = uosc;

  }
}

////////////////////////////////////////////////////////////////////////////////////////////////////////////////////////////////////

void loop()
{
DDS();
CONTROLS ();
KEYS ();
GLIDE();
SHIFT();
WAVESELECT();
ARP();
LFO();
RECORD();
}

////////////////////////////////////////////////////////////////////////////////////////////////////////////////////////////////////

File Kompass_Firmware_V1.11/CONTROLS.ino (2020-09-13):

void CONTROLS(){ 
   
  if (oscswitch==1){
    IR();
    if (tunemode!=1 && recordlatch!=1){    //standard
      
   glidebutton = digitalRead(1);
    //   glidebutton = 1;
      shiftbutton = digitalRead(0);
      irswitch = digitalRead(2);
      wavepot=(analogRead(3))>>6;
      lfopot= (analogRead(0));
    // apot = (analogRead(5))<<4; arppot = 1;
     arppot = (analogRead(1));
    }
    
    if (tunemode==1){
      tempermentbutton = digitalRead(1);
      shiftbutton = digitalRead(0);
      wavepot=(analogRead(3));
      offsetpot=0;
      // offsetpot=(((analogRead(5))>> 7)-2)*12;
      keypot= (analogRead(4));
      // apot = (analogRead(5))/32; arppot = 1;
      arppot = 0;

      if (keypot<=4)
      {
        temperment=0;
      }

      if (keypot>4 && keypot<512)
      {
        temperment=1;
        keypotm=map(keypot,4,512,-11,11);
      }
      if (keypot>=512)
      { 
        temperment=2;
        keypotm=map(keypot,512,1020,-11,11);
      }
 

    }
    
    if (recordlatch==1){
       arppot = (analogRead(1));
      restbutton = digitalRead(1);
      recordbutton = digitalRead(0);
      irswitch = digitalRead(2);
      wavepot=(analogRead(3))>>6;
      lfopot= (analogRead(0));
    }
    
  }
  if (oscswitch==2){

    if (uosc>200){
      digitalWrite(13, HIGH);  
    }
    if (uosc<=200){
      digitalWrite(13, LOW);  
    }

    shiftbutton = digitalRead(0);

    irswitch = 0;
    dswitch=digitalRead(2);
    wavepot=127;
    waveoff=(analogRead(3))+128;
    lfopot = (analogRead(0));
    arppot = 1;
    bpot = (analogRead(1));
       epot = bpot >> 5;
       fpot= (bpot<<12)-4194304;
       gpot= bpot*4;
    dronemodebutton= digitalRead(1);
    if (dronemodebutton != prevdronemodebutton){
      if (dronemodebutton == HIGH) {
        dronemode++;
      }     

      else{

      }
      prevdronemodebutton = dronemodebutton;
    }
  }
}

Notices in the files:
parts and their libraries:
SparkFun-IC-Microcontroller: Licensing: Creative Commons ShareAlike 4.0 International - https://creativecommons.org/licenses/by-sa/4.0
